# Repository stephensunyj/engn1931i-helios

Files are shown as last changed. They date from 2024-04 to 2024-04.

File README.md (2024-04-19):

# ENGN 1931I Final Project - Helios
### Helios - The Integrated, Inexpensive Smart Shade & Alarm System

Ever felt tired reaching for your blinds every day? Ever wanted to wake up to natural light? Helios is the product for you! Helios is a  set of smart window blinds that can raise, lower and rotate through voice commands. It also comes with a separate unconnected alarm clock unit, that when ringing, will also automatically raise the blinds to wake the user up through natural light. 

We used stepper motors and 2 Arduino Unos to control the blinds and alarm clock respectively, and a HC12 wireless chip to communicate wirelessly between the blinds and alarm clock. BitVoicer was used for the voice communication functionality.

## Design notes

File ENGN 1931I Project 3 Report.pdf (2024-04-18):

Aliya Chambless, Tyler Jacobson, Stephen Sun Prof. R. Iris Bahar
ENGN 1931I: Design of Robotic Systems

### 7 April 2021

## Project 3: Signal Processing Report

### 1. A well-commented version of the Arduino sketches used for demoing your

project (with appropriate citations). Please upload your .ino file(s) in addition to putting your code in your report Appendix.
Refer to appendix 1.

### 2. A discussion of your design concept and its evolution and how it is meant to

integrate into your final project.

The concept for this project was based on a problem that many city-dwellers have. These residents want their window shades closed at night to help them fall asleep, preventing city lights from blaring in their room at night, yet want to be woken up with natural light in the morning. While raising and lowering the blinds every night manually could work, this still does not allow the resident to be woken up by natural light. Our original concept was a pair of “smart shades” in which a photosensor alone could lower and raise shades and a voice-command system could be used to change the position of the blinds hands-free. We decided to conduct user and precedent research to identify what problems users had with their current shades and what features they might like to see in such smart shades.

Our initial user research revealed that users wanted simplicity in using the shades. For example, the users that wanted to use the shade as an alarm did not want to have to set a second auditory alarm to make sure they woke up. To address this, we added sound capability to the alarm sequence. We also learned that users use blinds for the insulation benefits, but still wanted to enjoy natural light when they were using the room. This led to the idea of adding a motion sensor to track if a person is present in the room before closing the shades for insulation. We confirmed that voice control would be a useful addition to the product when the user is unable to get to the window, which could be for various reasons, from a zoom call to mobility issues.

For this project, we wanted to test the functionality of a minimum viable voice recognition and motor control software. This includes voice recognition that could rotate a stepper motor, rotate a stepper motor for a certain time period then rotate it back in the opposite direction, and set a timer that would rotate the motor and sound an alarm upon completion. The voice control software that we used was BitVoicer Server. (http://www.bitsophia.com/en-US/BitVoicerServer/Overview.aspx) This program makes use of Windows’ speech recognition and speech synthesis tools to run speech recognition on recorded audio clips. It can also read out phrases out loud that you set in the program. BitVoicer provides an Arduino library that allows the Arduino to interface with the program via the Serial port. The PC’s system microphone, or a microphone connected to the Arduino can be used for speech recognition. The library allows for two way communication, with first any audio from the Arduino being sent to BitVoicer Server, and then whatever data we set up to send on a voice command being recognized being transmitted back to the Arduino. In our case, we set up specific phrases that

ENGN 1931I: Design of Robotic Systems

### 7 April 2021

will trigger functions on the Arduino that each correspond to one function of the smart shades, for instance raising or lowering the blinds.

This stepper motor, together with the Arduino running the voice control code, will serve as the control system for the fully integrated “Helios” product. The stepper motor would be used to raise and lower the blinds and the alarm. A second servo motor can be used to control a tilt rod that rotates slats in the blinds to let in variable levels of light permeate into a room. Additional functionality can be easily layered into the control system as well. For example, motion sensors will be easily integrated into the final design such that when a person enters a room, the shades raise, and vice-versa.

### 3. A discussion of challenges encountered with the implementation of your

design.
We based our alarm system on Ken Silverman’s code, but he used a custom song format so we could not directly convert midi files to fit his code. We also observed that playing chords, or multiple frequencies at once, muddied the sound when played through a piezo or cheap buzzer. In order to play a loud and clear song, we converted notes using Max MSP’s midiparse object and created our own timing. We also modified Ken’s code to just play one frequency at a time.

The piezo was still pretty quiet, so we built a high pass filter circuit which made the sound more loud and clear. We had limited capacitor and resistor options, so we ended up using a 560 Ω resistor and a 100 microfarad capacitor. Following the formula 1/2πRCwe tried to raise the cutoff frequency slightly, but the only other capacitor we had was 100 picofarads, which would require a resistor in the hundreds of MΩ to get close to the current cutoff frequency.

The biggest area that we got stuck on was in the integration of the voice control and stepper code with the alarm audio processing code. We worked on these two areas separately, but when it came time to combine them together, we discovered that there was a big problem with getting the speaker to play sounds while the stepper motor was running. Once the stepper motor is initialized by creating a stepper object, the speaker’s sound becomes extremely distorted and very quiet.

Apart from testing the original Arduino stepper library, we tested 2 third party libraries: AccelStepper (https://www.airspayce.com/mikem/arduino/AccelStepper/index.html) as well as StepMotor. (http://mypractic.com/lesson-29-stepmotor-a-library-for-controlling-a-stepper-motor-in-the-arduino-system-timerone-library/) While both libraries claim to prevent blocking of the CPU, both libraries still caused distorted sound, and both libraries had other limitations. AccelStepper did not have a straightforward function that allows us to set how many steps to move. Instead, it requires a setting of a reference zero position and then the user provides target positions that are relative to the zero position. While this would allow for more precise control of the stepper motor, in our application we do not require this sort of precision, and simply setting the number of revolutions to turn to fully raise or lower our blinds should be sufficient. With StepMotor, the library makes use of interrupts on Timer 1 or 2 to move the stepper motor. Since the audio processing code uses Timer 2, we theoretically could use Timer 1 for controlling the stepper

ENGN 1931I: Design of Robotic Systems

### 7 April 2021

motor. However, even if we do use Timer 1, we are still running 2 interrupts on the Arduino at the same time. If 1 interrupt is triggered and we are running the interrupt service routine, any triggering of the other interrupt will be missed. In our testing, this caused the stepper motor to move, and no sound to be emitted from the speaker at all.

While we did consider changing to a DC motor, a stepper motor would still be best for our application, since stepper motors can provide much higher holding torque. A potential solution to our issue will be to have 2 Arduinos in communication, either through I2C or SPI, or even wirelessly with a wireless communication module. One Arduino will be involved in handling the voice and stepper motor control, while the other Arduino will run the interrupt based alarm code. The Arduino connected to voice control can send a packet to the other Arduino telling it how long of a duration to wait before triggering the alarm. When the alarm is triggered the second Arduino can tell the first Arduino to raise or lower the blinds as required, perhaps to let in natural light to help the user wake up.

4. A brief discussion of how the work was divided among team members.

Stephen worked mainly on getting the voice control program to work, and integrating it with the Arduino code. Aliya worked on the user research and modified the provided audio example code to work with a custom tune. Tyler worked on testing stepper and DC motors for use with our system, and also worked on the presentation.

5. Suggestions for improvements for this assignment (in future years).

We were initially confused about the importance and benefits of timer interrupts, and if time permits we thought that an individual signal processing lab would have been helpful between the last two projects.

#include <Stepper.h>

#include <BVSP.h>

#define STEPS 2038 // the number of steps in one revolution of your motor (28BYJ-48)

// define stepper motor - connected to pin 5-8
Stepper stepper(STEPS, 5, 7, 6, 8);

// Defines the constants that will be passed as parameters to // the BVSP.begin function
const unsigned long STATUS_REQUEST_TIMEOUT = 1000;

ENGN 1931I: Design of Robotic Systems

### 7 April 2021

const unsigned long STATUS_REQUEST_INTERVAL = 2000;

// Defines the size of the receive buffer
const int RECEIVE_BUFFER_SIZE = 2;

// variable for tracking the time
unsigned long timerStart = 0;
unsigned long alarmStart = 0;

// Takes 10s for stepper to rotate 2 revolutions at 12rpm const int blindsRaiseLowerTime = 10000;

// wait time for how long blinds should be lowered for int waitTime = 0;
int alarmTime = 0;

// Initializes a new global instance of the BVSP class BVSP bvsp = BVSP();

// buffer for receiving data from BitVoicer defined // Just a byte array
byte receiveBuffer[RECEIVE_BUFFER_SIZE];

// assume blinds are raised at boot
boolean blindsLowered = false;

/// disable alarm at the start boolean soundEnabled = false;

static const uint8_t wavlut[256] =
{
0, 1, 2, 3, 4, 5, 6, 7, 8, 9, 10, 11, 12, 13, 14, 15, //sawtooth wave
16, 17, 18, 19, 20, 21, 22, 23, 24, 25, 26, 27, 28, 29, 30, 31,
32, 33, 34, 35, 36, 37, 38, 39, 40, 41, 42, 43, 44, 45, 46, 47,
48, 49, 50, 51, 52, 53, 54, 55, 56, 57, 58, 59, 60, 61, 62, 63,
64, 65, 66, 67, 68, 69, 70, 71, 72, 73, 74, 75, 76, 77, 78, 79,
80, 81, 82, 83, 84, 85, 86, 87, 88, 89, 90, 91, 92, 93, 94, 95,
96, 97, 98, 99, 100, 101, 102, 103, 104, 105, 106, 107, 108, 109, 110, 111, 112, 113, 114, 115, 116, 117, 118, 119, 120, 121, 122, 123, 124, 125, 126, 127,
128, 129, 130, 131, 132, 133, 134, 135, 136, 137, 138, 139, 140, 141, 142, 143,
144, 145, 146, 147, 148, 149, 150, 151, 152, 153, 154, 155, 156, 157, 158, 159,
160, 161, 162, 163, 164, 165, 166, 167, 168, 169, 170, 171, 172, 173, 174, 175,

ENGN 1931I: Design of Robotic Systems

### 7 April 2021

176, 177, 178, 179, 180, 181, 182, 183, 184, 185, 186, 187, 188, 189, 190, 191,
192, 193, 194, 195, 196, 197, 198, 199, 200, 201, 202, 203, 204, 205, 206, 207,
208, 209, 210, 211, 212, 213, 214, 215, 216, 217, 218, 219, 220, 221, 222, 223,
224, 225, 226, 227, 228, 229, 230, 231, 232, 233, 234, 235, 236, 237, 238, 239,
240, 241, 242, 243, 244, 245, 246, 247, 248, 249, 250, 251, 252, 253, 254, 255,

};

static const PROGMEM char mysong_snd[] =
{
// numbers correspond to keys on a pianos (MIDI note shifted down ) //beach.snd:
0, 8, 77, 4, 79, 4, 81, 4,
84, 12, 77, 8, 76, 8, 86, 8
};

static const unsigned int freq[74] = //convert MIDI-like note values to frequencies (proportional to Hertz)
{
0,
523, 554, 587, 622, 659, 698, 740, 784, 831, 880, 932, 988, 1047, 1109, 1175, 1245, 1319, 1397, 1480, 1568, 1661, 1760, 1865, 1976, 2093, 2217, 2349, 2489, 2637, 2794, 2960, 3136, 3322, 3520, 3729, 3951, 4186, 4435, 4699, 4978, 5274, 5588, 5920, 6272, 6645, 7040, 7459, 7902, 8372, 8870, 9397, 9956, 10548, 11175, 11840, 12544, 13290, 14080, 14917, 15804,
16744, 17740, 18795, 19912, 21096, 22351, 23680, 25088, 26580, 28160, 29834, 31609,
33488,
};

#define NCHANS 4

static volatile uint16_t sampleIdx;
static volatile uint16_t sampleInc;

int speakerPin = 11; // using Timer2, interrupts are associated with pins 3 and 11
// pin 11 = OC2A, pin 3 = OC2B

void setup() {
// Starts serial communication at 115200 baudrate Serial.begin(115200);

ENGN 1931I: Design of Robotic Systems

### 7 April 2021

// Sets the Arduino serial port that will be used for
// communication, how long it will take before a status request // times out and how often status requests should be sent to // BitVoicer Server.
bvsp.begin(Serial, STATUS_REQUEST_TIMEOUT, STATUS_REQUEST_INTERVAL);

// Defines the function that will handle the frameReceived // event which is when data is received from bitvoicer bvsp.frameReceived = BVSP_frameReceived;
// enable the builtin led and the speaker pin for output pinMode(LED_BUILTIN, OUTPUT);
pinMode(speakerPin, OUTPUT);

// enable interrupts
interrupts();

//Timer 2 setup
TCCR2A = (1 << COM2A1) | (1 << COM2A0) //COM2A: controls OC2A/Arduino pin

### 11 output mode

| (1 << COM2B1) | (1 << COM2B0) //COM2B: controls OC2B/Arduino
pin 3 output mode
| | (0 << WGM21) | (1 << WGM20); //WGM: Phase correct PWM
(doubles period)
TCCR2B = (0 << WGM22)
| (1 << CS20); | //Timer2:prescaler=1
TIMSK2 = (1 << TOIE2); | //Enable Timer2 Overflow Interrupt
TIFR2 = (1 << TOV2); | //Clear TOV2 / clear pending
interrupts

}

#define NOTETIME 48 // smallest play time for a note unsigned long previousMillis = 0;

unsigned int chordTime = NOTETIME;
int songIndex = 0;
int j = 512;
uint8_t pauseFlag = 0;
uint8_t filterFlag = 0;

// Function to raise the blinds, currently rotates 1 revolution at 12rpm (5s per revolution)
void raiseBlinds() {
// Check if blinds are lowered, if blinds are already up do nothing
if (blindsLowered) {

ENGN 1931I: Design of Robotic Systems

### 7 April 2021

stepper.setSpeed(12);
stepper.step(STEPS);
blindsLowered = false;
}
}
// Function to lower the blinds, currently rotates 1 revolution at 12rpm (5s per revolution)
void lowerBlinds() {
// Check if blinds are not lowered. If blinds are already down do nothing if (!blindsLowered) {
stepper.setSpeed(12);
stepper.step(-STEPS);
blindsLowered = true;
}
}

// Function that lowers blinds for certain amount of time. Gets the current time
// and stores it in timerStart
void lowerBlindsTime() {
digitalWrite(LED_BUILTIN, HIGH); stepper.setSpeed(12);
stepper.step(-STEPS * 2);
blindsLowered = true;
timerStart = millis();
}

// Function that raises blinds for certain amount of time. Sets timerStart to 0
// which stops the code from checking if its time to raise blinds
void raiseBlindsTime() {
digitalWrite(LED_BUILTIN, LOW);
stepper.setSpeed(12);
stepper.step(STEPS * 2);
blindsLowered = false;
timerStart = 0;
}
// Function to enable the alarm. Sets alarmStart to 0
// which stops the code from checking if its time to ring alarm void enableAlarm() {
digitalWrite(LED_BUILTIN, HIGH);
soundEnabled = true;
alarmStart = 0;
}

void loop() {
// Checks if the status request interval has elapsed and if it

ENGN 1931I: Design of Robotic Systems

### 7 April 2021

// has, sends a status request to BitVoicer Server bvsp.keepAlive();
// Checks if there is data available at the serial port buffer // and processes its content according to the specifications
// of the BitVoicer Server Protocol
bvsp.receive();
// If the timer was started, check if its time to raise the blinds if (timerStart != 0) {
if (millis() >= timerStart + blindsRaiseLowerTime + waitTime) { raiseBlindsTime();
}
}
// If alarm was started, check if its time to ring the alarm if (alarmStart != 0) {
if (millis() >= alarmStart + alarmTime) { enableAlarm();
}
}
// Code for processing sound
unsigned char ch;
unsigned long currentMillis = millis(); // check if it's time to update chord
int f0, dl;
unsigned long deltaTime;

deltaTime = currentMillis - previousMillis;
if (!pauseFlag && (deltaTime >= NOTETIME))
{
// check if new command from keyboard was received and update waveform. // Serial.available waits for ENTER before updating waveform parameters. if (Serial.available())
{
ch = Serial.read();
if (ch == '[') {
j -= 16;
Serial.println("decrease pitch"); }
else if (ch == ']') {
j += 16;
Serial.println("increase pitch"); }
else if (ch == 'f') {
filterFlag = !filterFlag;
Serial.print("FIR filter ="); Serial.println(filterFlag);
}
else if ((ch == 10) || (ch == 13)) { Serial.print("."); // ASCII 10 and 13 are LF and CR }

ENGN 1931I: Design of Robotic Systems

### 7 April 2021

else if (ch == 't') {
if (!soundEnabled) {
soundEnabled = true;
Serial.println("sound enabled"); }
else if (soundEnabled) {
soundEnabled = false;
Serial.println("sound disabled"); }
}
else Serial.println("bad char");
}

// read 4 notes (that make up chord) plus note time from program memory // read the MIDI notes from the songlist (4 notes in 1 chord)
f0 = pgm_read_byte(&mysong_snd[songIndex ]);
dl = pgm_read_byte(&mysong_snd[songIndex + 1]);

chordTime = dl * NOTETIME;
songIndex = (songIndex + 2) % sizeof(mysong_snd); // start reading songs from beginning when done
pauseFlag = 1;

// convert note to frequency and adjust for pitch (shift by 12 to account for scaled integer and precision of table
// indicates how fast you should be traversing the waveform array. A high frequency sound means you need to take large
// steps (increments) through the waveform array. A low frequency sound means you need to take small step through the waveform.
sampleInc = (freq[f0] * (long)j) >> 12;
}

if (deltaTime >= (NOTETIME + chordTime))
{
//force slight pause after each note sampleInc = 0;

pauseFlag = 0;
previousMillis = currentMillis;
}
}

// Handles the frameReceived event
// BitVoicer supports payloads up to 1023 bytes - payloadSize is passed from // BitVoicer to Arduino as a parameter here, along with dataType
void BVSP_frameReceived(byte dataType, int payloadSize)
{
// Checks if the received frame contains binary data

ENGN 1931I: Design of Robotic Systems

### 7 April 2021

// 0x01 = Binary data (byte array)
// Can check for and use other data types here
if (dataType == DATA_TYPE_BINARY)
{
// If 2 bytes were received, process the command.
// getReceivedBytes returns the no. of bytes copied ot the buffer if (bvsp.getReceivedBytes(receiveBuffer, RECEIVE_BUFFER_SIZE) == RECEIVE_BUFFER_SIZE)
{
// If first byte is 1, raise blinds
if (receiveBuffer[0] == 0x01) { digitalWrite(LED_BUILTIN, LOW); raiseBlinds();
}
// If first byte is 2, lower blinds else if (receiveBuffer[0] == 0x02) { digitalWrite(LED_BUILTIN, HIGH);
lowerBlinds();
}
// If first byte is 3, lower the blinds for certain time else if (receiveBuffer[0] == 0x03) {
// Retrieve the wait time from the 2nd byte
waitTime = (int) receiveBuffer[1];
if (!blindsLowered) {
lowerBlindsTime();
}
// If the first byte is 3, set alarm
else if (receiveBuffer[0] == 0x04) {
// record the time that we started the alarm // Once current time >= alarmStart + alarmTime, // its time to trigger the alarm
alarmStart = millis();
// Retrieve the alarm time from 2nd byte alarmTime = (int) receiveBuffer[1];
}
}
}
}
}
#define FILTERTAPS 8 | // The number of taps in the FIR filter

uint8_t values[FILTERTAPS] = {0, 0, 0, 0, 0, 0, 0, 0}; // to have a nice start up, fill the array with 0's

// Interrupt service routine
// interrupt every 512 cycles (16,000,000/512Hz=31250)
ISR (TIMER2_OVF_vect)
{
if (soundEnabled) {

ENGN 1931I: Design of Robotic Systems

### 7 April 2021

uint8_t temp;
uint8_t out;
static uint8_t k = 0; // pointer to circular buffer

// the interrupt is at a fix time period and outputs a specific voltage level for the speaker. This voltage represents the addition of 4
// waveforms (notes) at 4 different frequencies.
// The voltage is interpreted as a PWM duty cycle on the OC2A pin (pin 11).
// It is the same waveform (e.g., sine wave), sampled across a full period repeatedly, but
// at a sampling rate that corresponds to the frequency of the particular note.
values[k] = (wavlut[(sampleIdx >> 8)] >> 2);

// OCR2A is proportional to the output voltage. It represents the sum of the 4 waves at an instant for this sample

OCR2A = values[k];

// updated index into waveform lookup table for 4 notes of the chord sampleIdx += sampleInc;
}
}

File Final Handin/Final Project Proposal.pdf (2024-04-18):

Aliya Chambless, Tyler Jacobson, Stephen Sun Prof. R. Iris Bahar
ENGN 1931I: Design of Robotic Systems
5 April 2021
Final Project Proposal: Helios

Project Description:

Helios, the next generation of smart shades, will make it possible to control window blinds with voice commands and schedule the behavior of the blinds in the future. Smart shades make controlling the light in the room more accessible and can be used to adjust lighting while in a zoom meeting, create privacy while changing, or insulate a window during colder days. The scheduling feature can be used to allow the natural sunset to light up a room while blocking light pollution during the night, or even move the sunrise by slowly letting light in at a later time.

Precedent Research:

- Smart shades exist, but require a remote or app to control them
- Voice controlled shades usually require an existing smart home system
- https://www.serenashades.com/ has a lot of the features we want to implement (privacy, scheduled wake up time, follow the sun)
- This one has a vacancy sensor!!
- Minimize fading of expensive furniture
- Very expensive
- Needs a smart home system
- Installation is a big issue -- cant integrate into existing shades

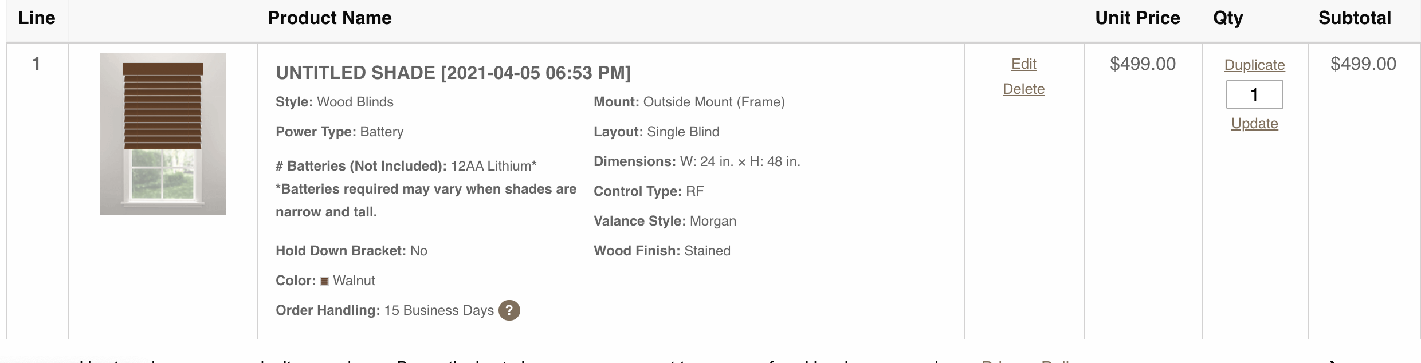
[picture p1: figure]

User Research Questions:

- What is the biggest frustration related to your windows?
- Hard to open
- Being sticky
- Lack of insulation -- (product could insulate)
- Shade doesn't sit easily
- Not tall enough to raise blind all the way
- What room do you change the blinds in most? Why?

- Living room -- cold/warm, how sunny
- Kitchen / living room -- roommates put blinds down
- When do you open/close your blinds?
- Changing in bedroom
- Light in the way of zoom call
- How much time do you typically spend with your blinds all the way up / light coming through?
- All the time
- Bedroom -- closed usually for privacy
- What time do you try to go to sleep?
- 11
- 1/2
- What makes it hard for you to fall asleep?
- Stress and anxiety
- Insomnia
- Does window light make it hard to fall asleep?
- No -- general night light (streetlights) doesn't bother her
- No --
- Does sunlight wake you up?
- Direct sunlight / car headlights wake her up
- Sudden changes in light
- Yes -- general morning light wakes him up
- What time do you like to wake up? Is it dark or light?
- After the sun comes up -- 9
- After the sun comes up -- 8:30/9
- Do you prefer to wake up to natural light or a dark room/with an alarm clock?
- Natural light
- Natural light -- sucks during winter
- Do you ever go back to sleep after closing the blinds?
- No
- No -- never closes blinds
- General Notes:
- Its in the black mirror --
- Wants it to beep at him -- fully integrated alarm
- Sounds like an alexa feature
- Some windows are hard to access
- Accessibility issues -- not able to close blinds

Personas:

- College Student with Insomnia (moving sunrise as an alarm)
- Always sleep deprived
- Very difficult to fall asleep and stay asleep
- Hard for them to wake up because they are always tired

- Need the light in the morning to get them up, but want to sleep in to catch up on sleep
- Wants to wake up to the sunrise, at 10am
- NYC resident (blocking light pollution but allowing for natural sunrise)
- Lots of light pollution -- street lights shining directly into room
- Wants to wake up with the natural sunrise but closes blinds at night to deal with light pollution
- Very cold in the winter and wants insulation, except when direct sunlight would be shining through the window
- Now works from home and wants to have good lighting during zoom calls
- Wheelchair user (controlling blinds with voice commands)
- Difficult for user to reach and use the blinds
- Hard to maneuver wheelchair to windows with obstacles (furniture)
- Wants the freedom to control their own blinds without asking for help
- Has multiple voice controlled devices in their home already and is comfortable with the technology, but doesnt want to activate other devices when controlling the shades

Addressing Issues From In-Class Proposal

The idea for Helios as pitched to the class was to have a window shade that opened when a certain light threshold was reached, typically in the morning, and closed when the light level fell below that threshold, typically in the evening. One piece of feedback we received was that users may not want the shades to fully open up at the beginning of the day, which could potentially let an extremely bright and uncomfortable sunlight pass through the window before one needs to wake. To address this issue, this design needs to 1) allow varying levels of light to pass through the window and 2) not open up immediately when that certain ambient light level has been reached. To resolve the first problem, the shades will either have slats oriented horizontally or vertically that could rotate. Since the slats do not need to rotate more than 180 degrees, this can be accomplished using a small servo motor connected to a string which pulls on the slats. A possible resolution to the second problem involves adding a programmable timer into the shade such that the shade opens at a certain time in the morning which the user sets beforehand. This could also be integrated with an alarm or buzzer that chimes a short jingle when the shades are opening up in the morning.

Sketches

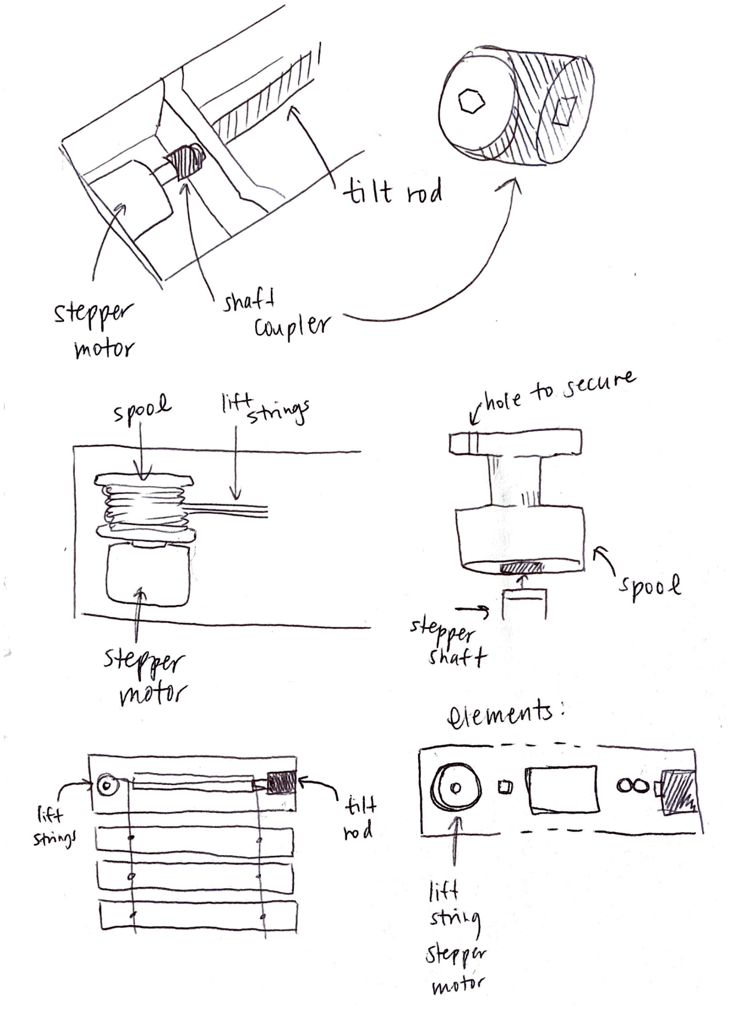
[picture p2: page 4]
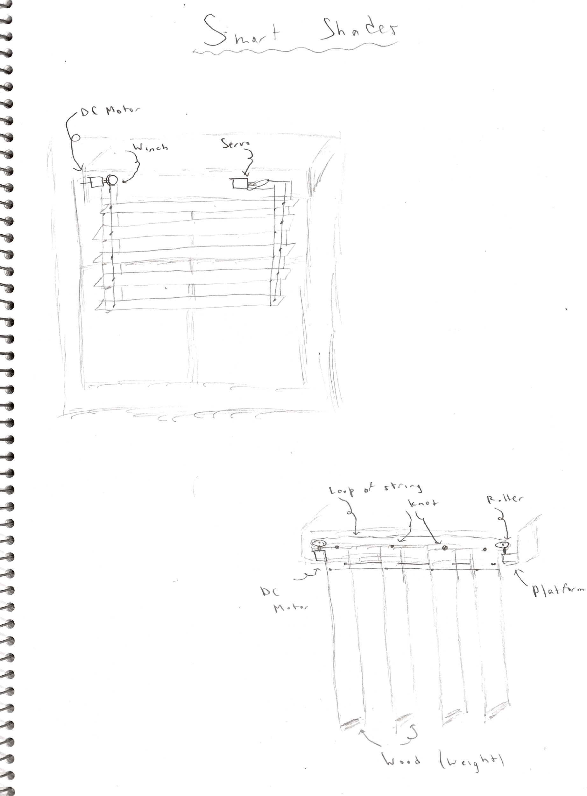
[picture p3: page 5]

Design Considerations

While we are unsure of the exact torques required to lift the slats up and down or left to right and rotate them, we will likely use two different types of motors to control them. Stepper motors allow for high torque and fine control over the number of rotations of the output shaft. Connecting the output shaft of a stepper motor to the winch or spool of string, which is connected to the center of an array of shade slats, will control whether the shades are deployed or not and how much. Two stepper motors on the left and right side of the shades will allow for symmetrical, synchronous and fine control. If we use a tilt rod to control raising and lowering of slats, only stepper one motor will be required. A servo motor, which only rotates 180 degrees, will be used to rotate the slats in either the horizontal or vertical configuration to let varying levels of light pass. This servo motor, which has a low torque output, nor the string connecting it to the slats themselves, will be supporting the weight of the slats.

Parts list

- Arduino Uno
- Windows laptop for running BitVoicer Server for voice recognition
- BitVoicer Server software -http://www.bitsophia.com/en-US/BitVoicerServer/Overview.aspx
- Adafruit MAX 4466 Electret Microphone Amplifier (used for recording voice commands from Arduino) - https://www.adafruit.com/product/1063 (included in kit)
- Stepper motors or DC motors for Moving blinds up and down
- Servo motors for rotating slat blinds(tentative) (included in kit)
- Set of blinds (tentative, we might build our own from scratch)
- Light sensor (photo cell) - https://www.adafruit.com/product/161 (included in kit)
- Piezo speaker - for outputting tones (included in kit)
- LCD display for displaying the time (tentative) (included in kit)

Components of robot

The stepper/DC motors and the servo motors will be used to actuate the blinds. While we are currently undecided on the type of blinds to use, if we choose to build the slats-style of blinds, the stepper/DC motors will be used to raise or lower the blinds, while the servo motors will rotate the angle of the slats. We could also attach a stepper motor directly to the tilt rod, instead of using two stepper motors. If we choose to build the single fabric-style of blinds, we will only utilize stepper/DC motors to raise or lower the blinds.

The BitVoicer Server software is the primary component that enables voice control of Helios. BitVoicer Server is a speech recognition and synthesis server for speech automation. The Arduino Uno does not have enough memory and processing power to perform advanced speech recognition and synthesis. BitVoicer Server eliminates the effects of these limitations by connecting to and using Windows’ speech recognition and synthesis tools.

BitVoicer Server is able to either parse speech input from the PC’s system microphone, or connect to the Arduino via a provided Arduino library. The Arduino library connects to an external microphone (in our case the Adafruit Electret Microphone) that is connected to an Arduino pin. BitVoicer Server then uses the Arduino’s serial port to send the received audio from the Arduino to the program itself. Once speech recognition is complete, BitVoicer Server will send back to the Arduino binary data in bytes. The Arduino library receives the data and stores it in a buffer which is readily usable by other portions of the code. The binary data can contain many things, for instance it can be used to transmit PWM values to a motor.

A light sensor, like a photo cell, can be used to detect ambient light levels. We plan to use this to implement the ability to automatically raise the blinds once there is sunlight in the morning, and automatically lower the blinds in the evening.

A piezo speaker will allow us to play sounds on the Arduino. This way, Helios will contain alarm clock functionality. Timer interrupts can be used to play the sounds. We can tentatively use an LCD display to display the current time as well.

Division of Work

Stephen: Voice control, programming, control flow
Tyler: Mechanical Design
Aliya: User Experience / Visual Design
Everyone: Written report, presentation, integration of 1 additional sensor

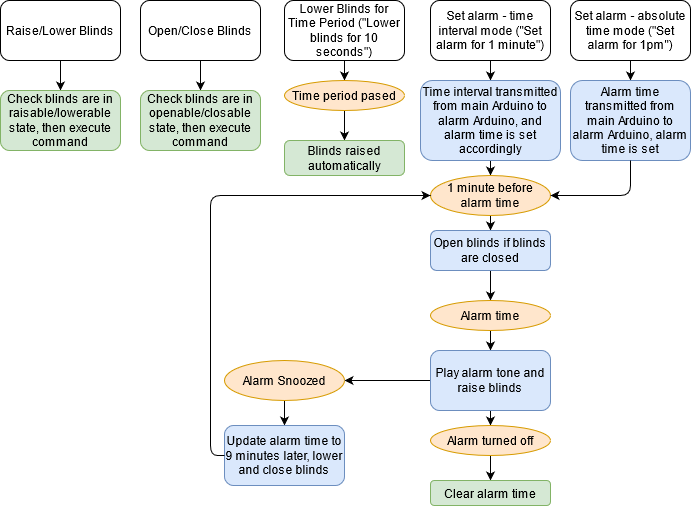
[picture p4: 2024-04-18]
function flow chart.png

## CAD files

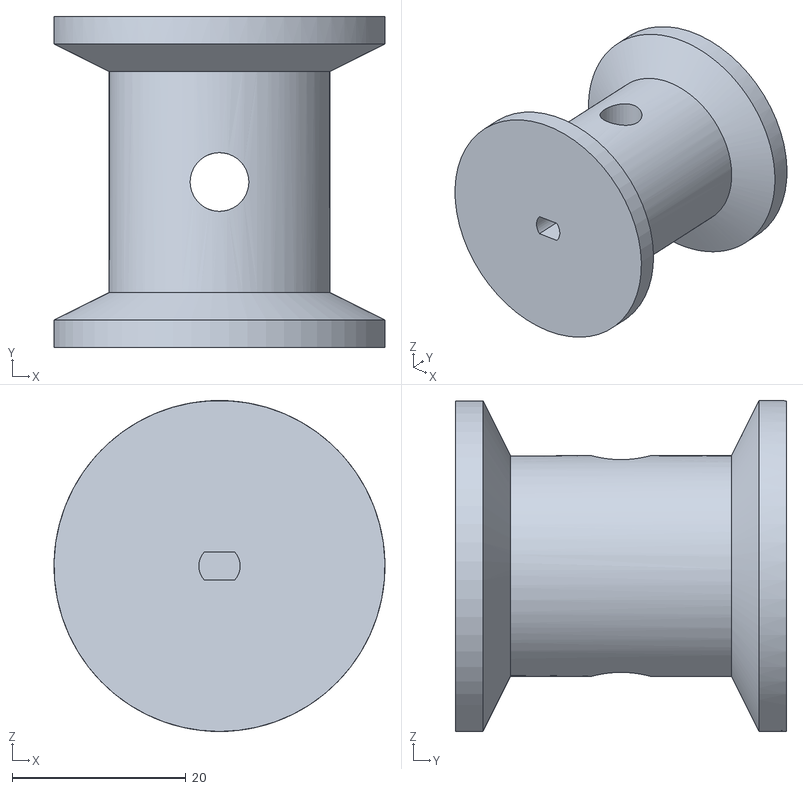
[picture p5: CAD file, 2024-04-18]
SpoolTwoMotor.STL
38.1 x 38.1 x 38.1

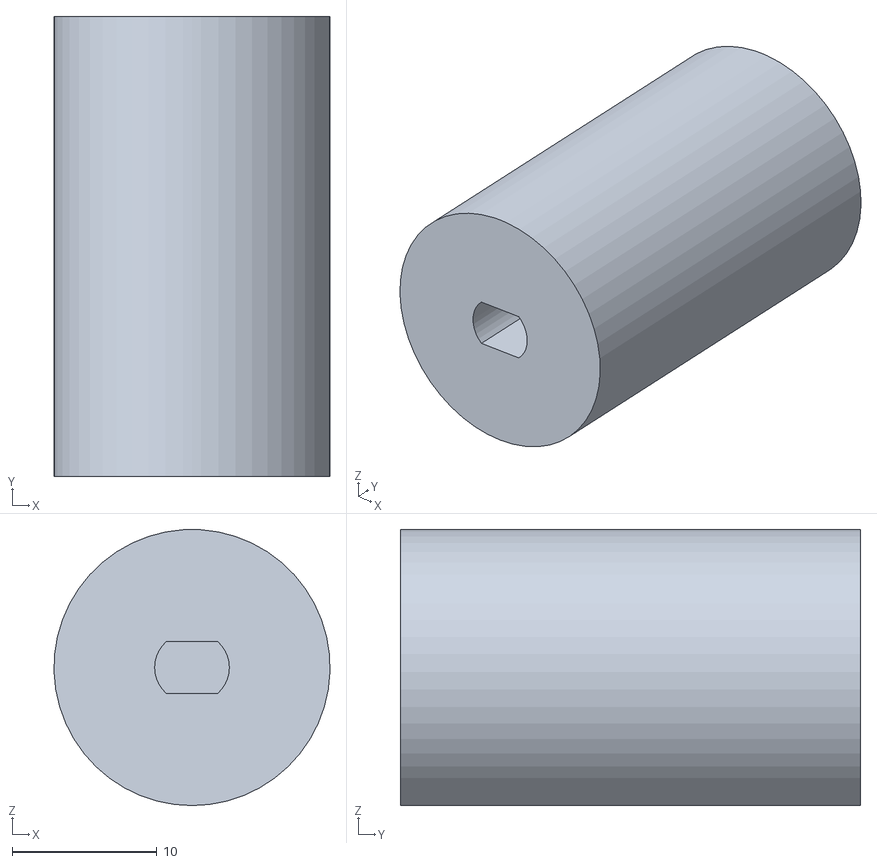
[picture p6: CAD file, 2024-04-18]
Coupler.STL
19.0 x 31.8 x 19.1

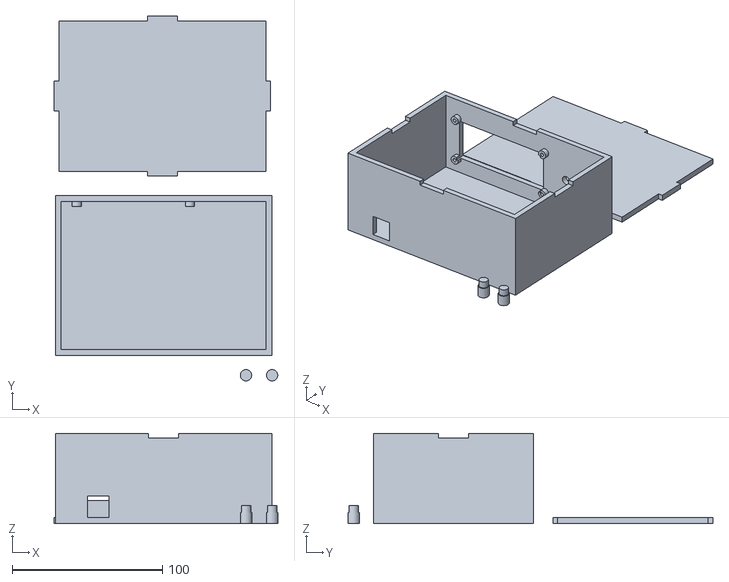
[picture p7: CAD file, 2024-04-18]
alarm-box.stl
148.8 x 242.7 x 60.0

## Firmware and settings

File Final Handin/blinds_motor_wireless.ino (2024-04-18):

#include <Stepper.h>
#include <BVSP.h>
#define STEPS 2038 // the number of steps in one revolution of your motor (28BYJ-48)
#include <SoftwareSerial.h>
SoftwareSerial HC12(10,11);

// define stepper motor for raising/lowering blinds - connected to pin 6-9
Stepper stepper(STEPS, 6, 8, 7, 9);
// define stepper motor for opening/closing blinds - connected to pins 2-5
Stepper rotationStepper(STEPS, 2, 4, 3, 5);

// Define no. of rotations of stepper motor for various blinds operations
float raiseBlindsRotations = 5.5;
float lowerBlindsRotations = -4.5;
float closeBlindsRotations = 6.0;
float openBlindsRotations = -6.0;

// Defines the constants that will be passed as parameters to
// the BVSP.begin function
const unsigned long STATUS_REQUEST_TIMEOUT = 1000;
const unsigned long STATUS_REQUEST_INTERVAL = 2000;

// Defines the size of the receive buffer
const int RECEIVE_BUFFER_SIZE = 4;

// variable for tracking the time
unsigned long timerStart = 0;
unsigned long alarmStart = 0;

// wait time for how long blinds should be lowered for
int waitTime = 0;

// Initializes a new global instance of the BVSP class
BVSP bvsp = BVSP();

// buffer for receiving data from BitVoicer defined
// Just a byte array
byte receiveBuffer[RECEIVE_BUFFER_SIZE];

// assume blinds are lowered at boot
boolean blindsLowered = true;

// assume blinds open at boot
boolean blindsClosed = false;

boolean soundEnabled = true;

void setup() {
  // Starts serial communication at 115200 baudrate
  Serial.begin(115200);
  HC12.begin(9600);
  // Sets the Arduino serial port that will be used for
  // communication, how long it will take before a status request
  // times out and how often status requests should be sent to
  // BitVoicer Server.
  bvsp.begin(Serial, STATUS_REQUEST_TIMEOUT,
             STATUS_REQUEST_INTERVAL);

  // Defines the function that will handle the frameReceived
  // event which is when data is received from bitvoicer
  bvsp.frameReceived = BVSP_frameReceived;
  // set up builtin led for output
  pinMode(LED_BUILTIN, OUTPUT);
  // turn on led since blinds are assumed to be down at the start
  digitalWrite(LED_BUILTIN, HIGH);

}

// Function to raise the blinds, currently rotates 1 revolution at 10rpm (6s per revolution)
void raiseBlinds() {
  // Check if blinds are lowered, if blinds are already up do nothing
  if (blindsLowered) {
    digitalWrite(LED_BUILTIN, LOW);
    stepper.setSpeed(10);
    stepper.step(raiseBlindsRotations*STEPS);
    blindsLowered = false;
  }
}

// Function to lower the blinds, currently rotates 1 revolution at 10rpm (6s per revolution)
void lowerBlinds() {
  // Check if blinds are not lowered. If blinds are already down do nothing
  if (!blindsLowered) {
    digitalWrite(LED_BUILTIN, HIGH);
    stepper.setSpeed(10);
    stepper.step(lowerBlindsRotations*STEPS);
    blindsLowered = true;
  }
}
// Function that lowers blinds for certain amount of time. Gets the current time
// and stores it in timerStart
void lowerBlindsTime(){
  digitalWrite(LED_BUILTIN, HIGH);
  stepper.setSpeed(12);
  stepper.step(lowerBlindsRotations*STEPS);
  blindsLowered = true;
  timerStart = millis();
}

// Function that raises blinds for certain amount of time. Sets timerStart to 0
// which stops the code from checking if its time to raise blinds
void raiseBlindsTime(){
  digitalWrite(LED_BUILTIN,LOW);
  stepper.setSpeed(12);
  stepper.step(raiseBlindsRotations*STEPS);
  blindsLowered = false;
  timerStart = 0;
}

// Function to close blinds
void closeBlinds(){
  // Check if blinds are currently open
  if(!blindsClosed){
    // Set speed and rotate stepper
    rotationStepper.setSpeed(12);
    rotationStepper.step(closeBlindsRotations*STEPS);
    blindsClosed = true;
  }
}

// Function to open blinds
void openBlinds(){
  // Check if blinds are currently closed
  if(blindsClosed){
    // Set speed and rotate stepper
    rotationStepper.setSpeed(12);
    rotationStepper.step(openBlindsRotations*STEPS);
    blindsClosed = false;
  }
}


void loop() {
  // Checks if the status request interval has elapsed and if it
  // has, sends a status request to BitVoicer Server
  bvsp.keepAlive();
  // Checks if there is data available at the serial port buffer
  // and processes its content according to the specifications
  // of the BitVoicer Server Protocol
  bvsp.receive();
  // If the timer was started, check if its time to raise the blinds
  if(timerStart != 0){
    if(millis() >= timerStart +  waitTime){
      raiseBlindsTime();
    }
  }

  // Receive data from alarm Arduino
  if(HC12.available()){
      // Convert received byte to int and parse it
      int readByte = (int) HC12.read();
      // If 1 received - raise blinds
      // This is sent by alarm Arduino when alarm starts ringing to let light in
      if(readByte == 1){
        raiseBlinds();
      }
      // If 2 received - lower blinds
      // This is sent by alarm Arduino when alarm is snoozed
      else if(readByte == 2){
        lowerBlinds();
      }
      // If 6 received - close blinds
      // This is sent by alarm Arduino when alarm is snoozed
      else if(readByte == 6){
        closeBlinds();
      }
      // If 7 received - open blinds
      // This is sent by alarm Arduino 1 minute before alarm time
      else if(readByte == 7){
        openBlinds();
      }
  }
}

// Handles the frameReceived event
// BitVoicer supports payloads up to 1023 bytes - payloadSize is passed from
// BitVoicer to Arduino as a parameter here, along with dataType
void BVSP_frameReceived(byte dataType, int payloadSize)
{
  // Checks if the received frame contains binary data
  // 0x01 = Binary data (byte array)
  // Can check for and use other data types here
  if (dataType == DATA_TYPE_BINARY)
  {
    // If 2 bytes were received, process the command.
    // getReceivedBytes returns the no. of bytes copied ot the buffer
    if (bvsp.getReceivedBytes(receiveBuffer, RECEIVE_BUFFER_SIZE) ==
        RECEIVE_BUFFER_SIZE)
    { 
      // Transmit data to alarm Arduino - data format specified in report
      for(int i=0;i<4;i++){
        HC12.write(receiveBuffer[i]);
      }
      Serial.println("receive frame");
      Serial.println(receiveBuffer[0]);
      // If first byte is 1, raise blinds
      if (receiveBuffer[0] == 0x01) {
        raiseBlinds();
      }
      // If first byte is 2, lower blinds
      else if (receiveBuffer[0] == 0x02) {
        lowerBlinds();
      }
      // If first byte is 3, lower the blinds for certain time
      else if(receiveBuffer[0] == 0x03){
        // Retrieve the wait time from the 2nd byte
        waitTime = (int) receiveBuffer[1];
        if(!blindsLowered){
        lowerBlindsTime();
        }
      }
        // If the first byte is 4, alarm time interval mode
          // next 3 bytes correspond to hour min sec respectively
          // hour - 0 to 255, minute - 0-60, second - 0-60
       // If first byte is 5, alarm absolute time mode
        // next 2 bytes correspond to hour and min respectively
        // 24 hour time - hour 0-24, min 0-60

      // If first byte is 6 - close blinds
       else if(receiveBuffer[0] == 0x06){
        // close blinds
        closeBlinds();
       }
       // if first byte is 7 - open blinds
       else if(receiveBuffer[0] == 0x07){
        openBlinds();
      }
    }
  }
}

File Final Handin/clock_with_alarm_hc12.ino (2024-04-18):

/*
 * Alarm Clock Code!
 * 
 * Clock functionality inspired by simplest_ever_UNO_digital_clock by plouc68000
 * https://create.arduino.cc/projecthub/plouc68000/simplest-uno-digital-clock-ever-4613aa
 */

#include <LiquidCrystal.h>
#include <SoftwareSerial.h>

SoftwareSerial HC12(8,9);
// define buffer for receiving data from hc12 chip
const int RECEIVE_BUFFER_SIZE = 4;
int receiveBuffer[RECEIVE_BUFFER_SIZE];

int h = 12;
int m = 58;
int s = 20;
int flag = 1; //PM

unsigned long last_loop;
unsigned long last_button_press;

int alarm[3];
int alarm_playing = 0;
int alarm_set = 0;
int pre_open = 0;
boolean new_alarm_time_received = false;

// Pins definition for Time Set Buttons
int hs = 6; // pin 0 for Hours Setting
int ms = 7; // pin 1 for Minutes Setting

LiquidCrystal lcd(12, 10, 5, 4, 3, 2);

//melody vars

int melody[] = {
  0, 698, 784, 880, 1046, 698, 659, 1175
};

int durations[] = {
  8, 4, 4, 4, 12, 8, 8, 8
};

const int alarm_pin = 11;
unsigned long last_note = 0;
int numberOfNotes = sizeof(melody) / sizeof(int);
int curr_note = numberOfNotes;


void setup() {
  Serial.begin(9600);
  HC12.begin(9600);
  lcd.begin(16, 2);
  last_loop = millis(); // read RTC initial value
  last_button_press = millis(); // fake button press

  pinMode(alarm_pin, OUTPUT);
}

void loop() {
  // print time on line 1
  lcd.setCursor(0, 0);
  lcd.print("Time ");
  if (h < 10)lcd.print("0");
  lcd.print(h);
  lcd.print(":");
  if (m < 10)lcd.print("0");
  lcd.print(m);
  // uncomment to add seconds to the clock
//   lcd.print(":");
//   if(s<10)lcd.print("0");
//   lcd.print(s);

  if (flag == 0) lcd.print(" AM");
  if (flag == 1) lcd.print(" PM");

  lcd.setCursor(0, 1); // for Line 2
  
  if (alarm_playing == 1) {
    lcd.print("Wake Up!!       ");
  } else if (alarm_set == 1) {
    lcd.print("Alarm: ");
    if (alarm[0] < 10)lcd.print("0");
    lcd.print(alarm[0]);
    lcd.print(":");
    if (alarm[1] < 10)lcd.print("0");
    lcd.print(alarm[1]);
    if (alarm[2] == 0) lcd.print(" AM");
    if (alarm[2] == 1) lcd.print(" PM");
  } else {
    lcd.print("                "); //clear the second line
  }


  if (millis() - last_loop > 997) {
    s = s + 1; // increment seconds 
    last_loop = millis();
  }

  int button1 = digitalRead(hs); // Read Buttons
  int button2 = digitalRead(ms);

  // button one pressed
  if(millis() - last_button_press > 200 and last_button_press < millis()) {
    if (button1 == 1) { //snooze
      if (alarm_playing) {
        alarm_playing = 0;
        alarm_set = 1;
        pre_open = 1;
        alarm[1] += 9; // add 9 mins to timer
        HC12.write(2); // lower the blinds 
        HC12.write(6); // close blinds 

        // increment clock properly
        if (alarm[1] > 60) {
          alarm[1] = alarm[1] - 60;
          alarm[0] = alarm[0] + 1;
          if(alarm[0] == 12) {
            alarm[2] = alarm[2] + 1;
  
            if (alarm[2] == 2) {
              alarm[2] = 0;
            }
          }
        }
        if (alarm[0] == 13) {
          alarm[0] = 1;
        }
        last_button_press = millis() + 2000; // don't allow button presses for 2 seconds after snooze
      } else {
        h = h + 1; // increment hours 
        if (h == 12) {
          flag = flag + 1;
      
          if (flag == 2)flag = 0;
        }
        last_button_press = millis();
      }
    }
  }

  // button two pressed
  if(millis() - last_button_press > 200 and last_button_press < millis()) {
    if (button2 == 1) {
      if (alarm_playing) {
        alarm_playing = 0; //stop the alarm
        alarm[0] = 0;
        last_button_press = millis() + 2000; // don't allow button presses for 2 seconds after stop
      } else {
        s = 0;
        m = m + 1; // increment minutes 
        if( m == 60 ) {
          m = 0;
        }
        last_button_press = millis();
      }
    }
  }

  // increment the clock
  if (s == 60) {
    s = 0;
    m = m + 1;
  }
  if (m == 60)
  {
    m = 0;
    h = h + 1;
    if (h == 12) {
      flag = flag + 1;

      if (flag == 2)flag = 0;
    }
  }
  if (h == 13)
  {
    h = 1;
  }

  //calculate the next minute to trigger pre-opening
  int next_time[3] = {h, m, flag};
  next_time[1] += 1;
  if (next_time[1] == 60)
  {
    next_time[1] = 0;
    next_time[0] = next_time[0] + 1;
    if (next_time[0] == 12) {
      next_time[2] = next_time[2] + 1;

      if (next_time[2] == 2)next_time[2] = 0;
    }
  }
  if (next_time[0] == 13)
  {
    next_time[0] = 1;
  }

  // pre-open the blinds 
  if (next_time[0] == alarm[0] and next_time[1] == alarm[1] and next_time[2] == alarm[2] and pre_open == 1) { // alarm sound
    Serial.println("open blinds");
    pre_open = 0;
    HC12.write(7); // open blinds 
  }
  
  // Ring the alarm
  if (h == alarm[0] and m == alarm[1] and flag == alarm[2] and s == 0 and alarm_playing == 0) { // alarm sound
    HC12.write(1); // raise the blinds 
    curr_note = 0;
    last_note = millis();
    alarm_playing = 1; //set the alarm flag
    alarm_set = 0;
  }

  // play alarm tones
  if (alarm_playing == 1) {
    if (curr_note < numberOfNotes) {
      tone(alarm_pin, map(melody[curr_note], 600, 1200, 200, 300)); //re-mapped original values to work with the sine wave tinkering

      if (millis() - last_note > (48 * durations[curr_note])) {
        curr_note ++;
        last_note = millis();
      }
    } else {
      curr_note = 0;
    }
  } else {
    noTone(alarm_pin);
  }
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
